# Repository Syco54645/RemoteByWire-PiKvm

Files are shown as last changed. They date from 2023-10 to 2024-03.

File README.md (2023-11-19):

# RemoteByWire-PiKvm
This project allows the control of an AIMOS 8 Port KVM via the PiKvm system. This was accomplished by replacing the IR receiver with an Arduino. In theory, this should work for other multi-port KVMs with an IR remote.

## Why Bother?
PiKVM is a fantastic project, the only issue is that it is single port only. This can be worked around by plugging in a multi-port KVM. There are a few plug and play options available but they were cost prohibitive. The AIMOS KVM will work but has a few shortcomings. First, it must be controlled by hotkeys. While this is not horrible, to use this method of control you must plug the USB into the keyboard port of the KVM. Doing this will break the USB mass storage emulation. To be fair, there is a workaround for the mass storage issue but it requires a second Raspberry Pi. This system allows direct control of the AIMOS KVM with a simple terminal script.

### Usage
This project consists of three parts.

 - [IrEmulator.ino](https://github.com/Syco54645/RemoteByWire-PiKvm/blob/main/IrEmulator/IrEmulator.ino) - Arduino software to perform the switching of inputs on the AIMOS KVM.
 - [pyRemoteByWireDaemon.py](https://github.com/Syco54645/RemoteByWire-PiKvm/blob/main/pyRemoteByWireDaemon.py "pyRemoteByWireDaemon.py") - Python script that connects to the Arduino via serial. It waits for a command to be sent to it from the [sendCmd.py](https://github.com/Syco54645/RemoteByWire-PiKvm/blob/main/sendCmd.py "sendCmd.py") script
 - [sendCmd.py](https://github.com/Syco54645/RemoteByWire-PiKvm/blob/main/sendCmd.py "sendCmd.py") - Python script to send commands to [pyRemoteByWireDaemon.py](https://github.com/Syco54645/RemoteByWire-PiKvm/blob/main/pyRemoteByWireDaemon.py "pyRemoteByWireDaemon.py")

#### [IrEmulator.ino](https://github.com/Syco54645/RemoteByWire-PiKvm/blob/main/IrEmulator/IrEmulator.ino)
Flash this to your Arduino. Theroritically this file could be modified to send different signals and work for other KVMs.

#### [pyRemoteByWireDaemon.py](https://github.com/Syco54645/RemoteByWire-PiKvm/blob/main/pyRemoteByWireDaemon.py "pyRemoteByWireDaemon.py")
`python pyRemoteByWireDaemon.py -s <USB SERIAL> -p 5555`

#### [sendCmd.py](https://github.com/Syco54645/RemoteByWire-PiKvm/blob/main/sendCmd.py "sendCmd.py")
`python sendCmd.py -p 5555 -s <KVM PORT NUMBER> `

### Skills
Basic soldering skills are a must. The most dangerous part is removing the IR receiver. the rest should just be simple soldering.

### BOM
 - PiKVM
 - Aimos 8 port KVM
 - Arduino Nano
 - Logic Level Converter

### Building
This project is relatively simple to build
 1. Disassemble the AIMOS KVM and remove the IR receiver

### Circuit
Below is a diagram of the circuit. The purple and black output wires connect to the AIMOS board, the purple goes where the output of the IR receiver was and the black goes to ground.
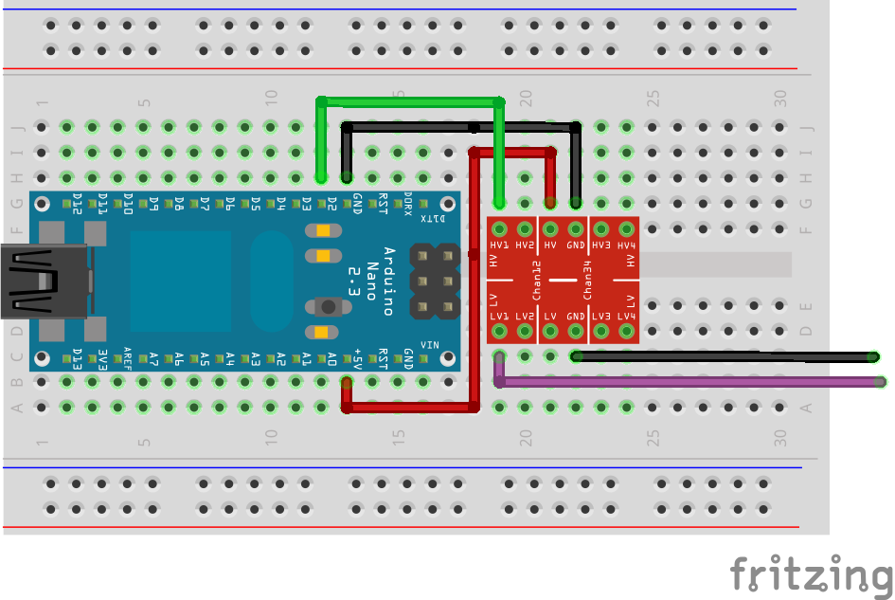
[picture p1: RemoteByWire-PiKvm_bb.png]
RemoteByWire-PiKvm Circuit


### Pi Setup
 - rw
 - pacman -S python-pip
 - pacman -S python-pyzmq
 - ls /dev/serial/by-id/

### /etc/kvmd/override.yaml
```
kvmd:
    ...
    gpio:
        drivers:
            btn1:
                type: cmd
                cmd: [/usr/bin/python, /usr/local/bin/sendCmd.py, -s, 1]
            btn2:
                type: cmd
                cmd: [/usr/bin/python, /usr/local/bin/sendCmd.py, -s, 2]
            btn3:
                type: cmd
                cmd: [/usr/bin/python, /usr/local/bin/sendCmd.py, -s, 3]
            btn4:
                type: cmd
                cmd: [/usr/bin/python, /usr/local/bin/sendCmd.py, -s, 4]
            btn5:
                type: cmd
                cmd: [/usr/bin/python, /usr/local/bin/sendCmd.py, -s, 5]
            btn6:
                type: cmd
                cmd: [/usr/bin/python, /usr/local/bin/sendCmd.py, -s, 6]
            btn7:
                type: cmd
                cmd: [/usr/bin/python, /usr/local/bin/sendCmd.py, -s, 7]
            btn8:
                type: cmd
                cmd: [/usr/bin/python, /usr/local/bin/sendCmd.py, -s, 8]
        scheme:
            btn1_button:
                driver: btn1
                pin: 0
                mode: output
                switch: false
            btn2_button:
                driver: btn2
                pin: 0
                mode: output
                switch: false
            btn3_button:
                driver: btn3
                pin: 0
                mode: output
                switch: false
            btn4_button:
                driver: btn4
                pin: 0
                mode: output
                switch: false
            btn5_button:
                driver: btn5
                pin: 0
                mode: output
                switch: false
            btn6_button:
                driver: btn6
                pin: 0
                mode: output
                switch: false
            btn7_button:
                driver: btn7
                pin: 0
                mode: output
                switch: false
            btn8_button:
                driver: btn8
                pin: 0
                mode: output
                switch: false
        view:
            header:
                title: KVM Control
            table:
                 - ["btn1_button|Port 1"]
                 - ["btn2_button|Port 2"]
                 - ["btn3_button|Port 3"]
                 - ["btn4_button|Port 4"]
                 - ["btn5_button|Port 5"]
                 - ["btn6_button|Port 6"]
                 - ["btn7_button|Port 7"]
                 - ["btn8_button|Port 8"]
```

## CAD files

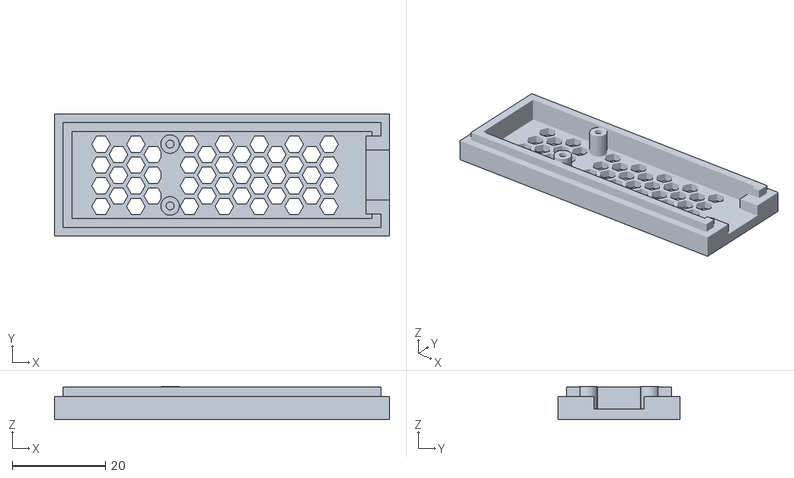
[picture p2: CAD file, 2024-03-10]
RemoteByWire-PiKvm Case.stl
72.0 x 26.2 x 7.20

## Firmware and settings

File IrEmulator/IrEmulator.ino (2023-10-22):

/*
* Arduino Application to control an AIMOS 8 port KVM by wire rather than IR LED.
* Copyright (C) 2023 Syco54645
*
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
* You should have received a copy of the GNU General Public License
* along with this program.  If not, see <http://www.gnu.org/licenses/>.
*/

#include <IrSenderNonMod.h>

static constexpr pin_t outPin = 2;

static const microseconds_t btn1Data[] = {
  9034, 4466, 596, 1644, 596, 538, 592, 540, 590, 544, 596, 536, 592, 540, 590, 544, 596, 536, 594, 540, 590, 1650, 590, 1676, 564, 1650, 590, 1650, 590, 1650, 590, 1650, 590, 1652, 590, 544, 596, 1644, 596, 1644, 596, 1644, 596, 1644, 596, 538, 592, 542, 588, 544, 596, 1644, 596, 538, 592, 542, 588, 544, 594, 538, 592, 1648, 594, 1646, 594, 1646, 594
};
static const IrSequence btn1(btn1Data, sizeof(btn1Data) / sizeof(microseconds_t));

static const microseconds_t btn2Data[] = {
  9026, 4470, 592, 1648, 592, 542, 588, 544, 596, 536, 592, 540, 590, 542, 596, 536, 594, 540, 590, 542, 598, 1644, 596, 1642, 598, 1642, 598, 1642, 598, 1644, 596, 1644, 596, 1644, 596, 536, 594, 538, 590, 1650, 590, 1650, 590, 1650, 650, 482, 596, 536, 594, 538, 590, 1650, 590, 1650, 590, 542, 598, 534, 594, 538, 592, 1648, 592, 1648, 592, 1648, 592
};
static const IrSequence btn2(btn2Data, sizeof(btn2Data) / sizeof(microseconds_t));

static const microseconds_t btn3Data[] = {
  9028,4470,592,1648,592,542,588,546,594,538,592,540,588,544,596,536,594,540,590,544,596,1644,596,1642,598,1642,598,1642,598,1668,572,1668,572,1670,570,1670,570,1670,570,538,592,540,590,542,596,536,594,540,590,544,596,536,594,540,590,1650,590,1648,592,1648,592,1650,592,1674,566,1676,564
};
static const IrSequence btn3(btn3Data, sizeof(btn3Data) / sizeof(microseconds_t));

static const microseconds_t btn4Data[] = {
  9032,4468,644,1596,594,540,590,542,596,536,594,540,590,542,596,536,594,540,590,542,596,1668,562,1652,590,1650,590,1650,590,1650,590,1650,590,1648,592,542,596,536,594,540,590,542,596,536,594,538,592,542,588,546,594,1670,570,1644,598,1642,598,1642,598,1642,598,1642,588,1652,590,1650,590
};
static const IrSequence btn4(btn4Data, sizeof(btn4Data) / sizeof(microseconds_t));

static const microseconds_t btn5Data[] = {
  9032,4468,594,1646,594,540,590,542,598,534,596,538,592,542,588,544,596,538,592,540,590,1650,590,1650,590,1650,590,1650,590,1650,590,1650,590,1652,588,1652,590,1650,590,1650,590,544,596,536,592,540,590,542,598,536,594,540,590,542,598,534,594,1646,594,1646,596,1644,596,1644,596,1644,596
};
static const IrSequence btn5(btn5Data, sizeof(btn5Data) / sizeof(microseconds_t));

static const microseconds_t btn6Data[] = {
  9036,4464,598,1642,588,544,596,538,592,540,588,544,596,536,594,540,590,542,598,536,594,1646,596,1644,596,1644,596,1644,596,1642,598,1642,598,1642,598,536,594,540,590,1674,566,540,588,544,596,538,592,540,590,544,596,1642,598,1642,598,534,596,1644,596,1642,598,1642,598,1642,590,1650,590
};
static const IrSequence btn6(btn6Data, sizeof(btn6Data) / sizeof(microseconds_t));

static const microseconds_t btn7Data[] = {
  9030,4470,592,1646,594,540,590,542,598,536,594,540,590,544,596,536,594,540,590,542,598,1642,598,1644,586,1652,588,1652,598,1644,598,1644,596,1644,596,1642,598,1642,588,544,594,1644,596,536,594,540,590,544,596,536,594,538,592,542,588,1650,590,544,596,1642,598,1642,598,1642,588,1652,588
};
static const IrSequence btn7(btn7Data, sizeof(btn7Data) / sizeof(microseconds_t));

static const microseconds_t btn8Data[] = {
  9030,4468,596,1670,570,538,592,540,588,544,596,536,594,540,590,542,596,536,594,538,592,1648,592,1648,592,1648,592,1648,592,1648,592,1648,592,1646,594,540,590,544,596,536,594,1646,594,538,592,540,590,542,598,536,594,1646,596,1644,596,1644,598,536,594,1646,594,1646,594,1646,596,1644,596
};
static const IrSequence btn8(btn8Data, sizeof(btn8Data) / sizeof(microseconds_t));

static IrSenderNonMod sender(outPin, true);

void setup() {
  Serial.begin(9600);
}

void loop() {
  if (Serial.available() > 0) {
    String data = Serial.readStringUntil('\n');
    //Serial.print("Received: ");
    //Serial.println(data);
    if (data == "btn1") {
      sender.sendNonModulated(btn1, 2);
      Serial.println("sw: btn1");
    } else if (data == "btn2") {
      sender.sendNonModulated(btn2, 2);
      Serial.println("sw: btn2");
    } else if (data == "btn3") {
      sender.sendNonModulated(btn3, 2);
      Serial.println("sw: btn3");
    } else if (data == "btn4") {
      sender.sendNonModulated(btn4, 2);
      Serial.println("sw: btn4");
    } else if (data == "btn5") {
      sender.sendNonModulated(btn5, 2);
      Serial.println("sw: btn5");
    } else if (data == "btn6") {
      sender.sendNonModulated(btn6, 2);
      Serial.println("sw: btn6");
    } else if (data == "btn7") {
      sender.sendNonModulated(btn7, 2);
      Serial.println("sw: btn7");
    } else if (data == "btn8") {
      sender.sendNonModulated(btn8, 2);
      Serial.println("sw: btn8");
    }
  }
  /*sender.sendNonModulated(btn1, 2);
  Serial.println("Sending btn1");
  delay(2000);
  
  sender.sendNonModulated(btn2, 2);
  Serial.println("Sending btn2");
  delay(2000);
  
  sender.sendNonModulated(btn3, 2);
  Serial.println("Sending btn3");
  delay(2000);
  
  sender.sendNonModulated(btn4, 2);
  Serial.println("Sending btn4");
  delay(2000);
  
  sender.sendNonModulated(btn5, 2);
  Serial.println("Sending btn5");
  delay(2000);
  
  sender.sendNonModulated(btn6, 2);
  Serial.println("Sending btn6");
  delay(2000);
  
  sender.sendNonModulated(btn7, 2);
  Serial.println("Sending btn7");
  delay(2000);
  
  sender.sendNonModulated(btn8, 2);
  Serial.println("Sending btn8");
  delay(2000);*/
}

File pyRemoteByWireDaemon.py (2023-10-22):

#
# Console Application Daemon to communicate with IrEmulator
# Copyright (C) 2023 Syco54645
#
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

#!/usr/bin/env python3
import serial
import time
import sys, getopt
import zmq
import signal

signal.signal(signal.SIGINT, signal.SIG_DFL); # allow ctrl-c to kill the app

ser = serial.Serial()
ser.baudrate = 9600
ser.timeout = 1

context = zmq.Context()
socket = context.socket(zmq.REP)

def interactiveMode():
    while True:
        value = input("Please enter 1-8: ")
        doSwitch(value)
        #line = ser.readline().decode('utf-8').rstrip()
        #print(line)

def daemonMode(port, serialPort):
    print(f"Daemon Started on tcp://*:%s. Waiting for command..." % port)
    print(f"Serial Port connected on %s. Ready to send command...\n" % serialPort)
    print("ctrl-c to exit\n")
    while True:
        message = socket.recv()
        print(">>> [%s]" % message)
        doSwitch(message)
        socket.send(b"done %s" % message)

def doSwitch(value):
    ser.reset_output_buffer()
    ser.reset_input_buffer()
    cmd = b"btn1\n"
    if isinstance(value, (bytes, bytearray)):
        cmd = value
    else:
        match value:
            case "1" | 1:
                cmd = b"btn1\n"
            case "2" | 2:
                cmd = b"btn2\n"
            case "3" | 3:
                cmd = b"btn3\n"
            case "4" | 4:
                cmd = b"btn4\n"
            case "5" | 5:
                cmd = b"btn5\n"
            case "6" | 6:
                cmd = b"btn6\n"
            case "7" | 7:
                cmd = b"btn7\n"
            case "8" | 8:
                cmd = b"btn8\n"
            case _:
                cmd = b"btn1\n"
    ser.write(cmd)
    line = ser.readline().decode('utf-8').rstrip()
    print(">>> [%s]" % line)

def main(argv):
    serialPort = 'COM3'
    port = "5555"
    mode = "daemon"
    opts, args = getopt.getopt(argv,"his:p:",["help","interactive","serial=","port="])

    for opt, arg in opts:
        if opt in ("-h", "--help"):
            print ('pyRemoteByWireDaemon.py -p <port> -s <number>\n')
            print ('-h, --help \t Shows this help screen.')
            print ('-s, --serial \t The serial port for daemon/arduino communication.')
            print ('-p, --port \t The web port for the daemon. Default is 5555.')
            print ('-i, --interactive \t Interactive mode bypasses the need of sendCmd. Good for debugging.')
            sys.exit()
        if opt in ("-s", "--serial"):
            serialPort = arg
        if opt in ("-p", "--port"):
            port = arg
        if opt in ("-i", "--interactive"):
            mode = "interactive"

    socket.bind(f"tcp://*:%s" % port)
    ser.port = serialPort
    ser.open()
    ser.reset_input_buffer()
    
    if mode == "interactive":
        interactiveMode()
    else:
        daemonMode(port, serialPort)

    ser.close()
    sys.exit()

if __name__ == '__main__':
    main(sys.argv[1:])

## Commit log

2023-10-22 moved files around for the arduino ide
2023-10-22 Modified the arduino code to listen for serial communication. Created python app to send the data to the arduino
2023-10-22 created python daemon to hold open a connection to the serial on the arduino. changed sendcmd to use the new daemon
2023-10-22 cleaned up the help screen. fixed longopts not working correctly.
    [pyRemoteByWireDaemon.py, sendCmd.py]
2023-10-23 Added fritzing diagram
    [RemoteByWire-PiKvm.fzz]
2024-03-10 Added case for the dongle
    [RemoteByWire-PiKvm Case.stl]

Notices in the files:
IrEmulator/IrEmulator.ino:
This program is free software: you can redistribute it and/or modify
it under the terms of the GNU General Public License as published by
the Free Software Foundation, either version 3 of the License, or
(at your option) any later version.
